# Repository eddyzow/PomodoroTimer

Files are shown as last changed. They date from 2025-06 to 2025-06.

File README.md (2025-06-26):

# PomodoroTimer
*i need to study and don't know how!*

# Build Photos





## Description

I've struggled with autism in early childhood and ADHD my entire life. It goes without saying that studying has never been the easiest thing for me. I've always been keen on finding interesting ways to improve study habits as a result! 

One of these strategies is the Pomodoro Timer, a special study method that involves 25 minutes of work and then 5 minutes of break. There's also the 52/17 method, which gives a 17-minute break after 52 minutes of studying. After not enjoying having to use a Pomodoro Timer on some random online websites, I decided that a beautiful physical device to allow me to use the Pomodoro Timer effectively would be a very cool thing to build for Highway! 

I decided to use a TFT LCD screen because I've never done any hardware work with displays nor have I done any work with SPI communication devices. This is the first of those for me!

Behold PomodoroTimer! A simple pomodoro timer with time adjustment function, swap between modes (normal, extended break, 52/17), and alarm. Powered by an Arduino Nano and contains minimalistic controls: just three momentary pushbutton switches and an EC11 rotary encoder on the side. Timer is shown through a 4.0" TFT LCD screen. Custom firmware written in Arduino. 

The case is slightly angled to present the buttons to the user in an ergonomic fashion. The entire design was created in Onshape CAD! Created for Hack Club's Highway program.

# Design Photos






# Case Design



# Wiring Diagram
V2: 
V1: 

# Firmware
Firmware was written in Arduino with a small amount of help from Gemini -- library being used is the Adafruit_ST7796S_kbv package and pin choices and wire routing is still my own!

# Bill of Materials
Note: cost is now less because I removed lots of stuff I could probably scavenge from another project and also optimized other products.

For a full BOM with links, visit https://docs.google.com/spreadsheets/d/1WLxYVnncp4hckqmgex7FmrPYrEnqb0mDVtI4Y9LR5lQ/edit?usp=sharing

| Item Name | Purpose | Item Source | Quantity | Unit Cost (includes taxes) | Cost |
|:---|:---|:---|---:|:---|:---|
| 5pc 12mm Momentary Pushbutton Switch | Buttons for mode, start/stop, and extend functions | Amazon | 1 | $8.59 | $8.59 |
| 2pc 12mm Latching Pushbutton Switch | Power button | Amazon | 1 | $7.43 | $7.43 |
| Clone Arduino Nano Board (2 Pack) | Logic / brains for the timer. Not sold individually!! | Amazon | 1 | $9.55 | $9.55 |
| 4.0" 480x320 TFT LCD Screen | Color screen to make the function of the timer beautiful  | Amazon | 1 | $18.37 | $18.37  |
| AA Battery Holder (4 AA) | Holds the batteries for the project | Amazon | 1 | $5.30 | $5.30 |
| 3.3V-5V Logic Level Shifter | Logic level shifter is necessary to communicate to the 3.3V LCD | Amazon | 1 | $7.95 | $7.95 |
| **TOTAL** | | | 6 | | **$57.19** |

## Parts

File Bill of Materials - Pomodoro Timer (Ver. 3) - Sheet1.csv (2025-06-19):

Bill of Materials / Pomodoro Timer
Eddy Zhao
Version 3.0 - 19 June 2025 | Update: removed a crap ton of stuff I could probably scavenge from another project + optimized BOM in light of the fact that i'm using amazon
Item Name | Purpose | Item Source | Quantity | Unit Cost (includes taxes) | Cost
5pc 12mm Momentary Pushbutton Switch | Buttons for mode, start/stop, and extend functions | Amazon | 1 | $8.59 | $8.59
2pc 12mm Latching Pushbutton Switch | Power button | Amazon | 1 | $7.43 | $7.43
Clone Arduino Nano Board (2 Pack) | Logic / brains for the timer. Not sold individually!! | Amazon | 1 | $9.55 | $9.55
4.0" 480x320 TFT LCD Screen | Color screen to make the function of the timer beautiful | Amazon | 1 | $18.37 | $18.37
AA Battery Holder (4 AA) | Holds the batteries for the project | Amazon | 1 | $5.30 | $5.30
3.3V-5V Logic Level Shifter | Logic level shifter is necessary to communicate to the 3.3V LCD | Amazon | 1 | $7.95 | $7.95
 |  |  |  |  | $0.00
 |  |  |  |  | $0.00
 |  |  |  |  | $0.00
 |  |  |  |  | $0.00
 |  |  |  |  | $0.00
 |  |  |  |  | $0.00
 |  |  |  |  | $0.00
TOTAL |  |  | 6 |  | $57.19
Already have:
EC11 Rotary Encoder + Knob
400-Point Breadboard
3D Printer Filament
M3 Screws and Nuts
Active Buzzer
Jumper Wires

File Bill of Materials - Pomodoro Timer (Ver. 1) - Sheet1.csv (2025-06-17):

Bill of Materials / Pomodoro Timer
Eddy Zhao
Version 1.0 - 17 June 2025
Item Name | Purpose | Item Source | Quantity | Unit Cost (includes taxes) | Cost
2pc 12mm Momentary Pushbutton Switch | Buttons for mode, start/stop, and extend functions | Amazon | 2 | $7.43 | $14.86
2pc 12mm Latching Pushbutton Switch | Power button | Amazon | 1 | $7.43 | $7.43
Clone Arduino Nano Board (3 Pack) | Logic / brains for the timer. Not sold individually!! | Amazon | 1 | $16.88 | $16.88
4.0" 480x320 TFT LCD Screen | Color screen to make the function of the timer beautiful | Amazon | 1 | $18.37 | $18.37
AA Battery Holder (4 AA) | Holds the batteries for the project | Amazon | 1 | $6.35 | $6.35
Soldering Iron | I didn't get a soldering iron grant yet... and this project requires it | Amazon | 1 | $12.74 | $12.74
Jumper Wires | To connect the various electronics on the project | Amazon | 1 | $7.42 | $7.42
3.3V-5V Logic Level Shifter | Logic level shifter is necessary to communicate to the 3.3V LCD | Amazon | 1 | $7.95 | $7.95
Passive Buzzer | To make sounds on input and alarm/timer | Amazon | 1 | $6.36 | $6.36
 |  |  |  |  | $0.00
 |  |  |  |  | $0.00
 |  |  |  |  | $0.00
 |  |  |  |  | $0.00
TOTAL |  |  | 10 |  | $98.36
Already have:
EC11 Rotary Encoder + Knob
400-Point Breadboard
3D Printer Filament
M3 Screws and Nuts

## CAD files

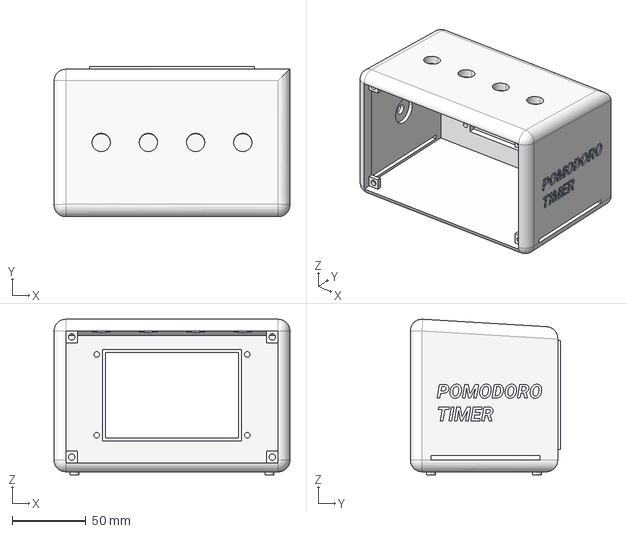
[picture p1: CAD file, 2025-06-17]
cad/Case - Pomodoro Timer.step
160.0 x 102.0 x 105.5 mm

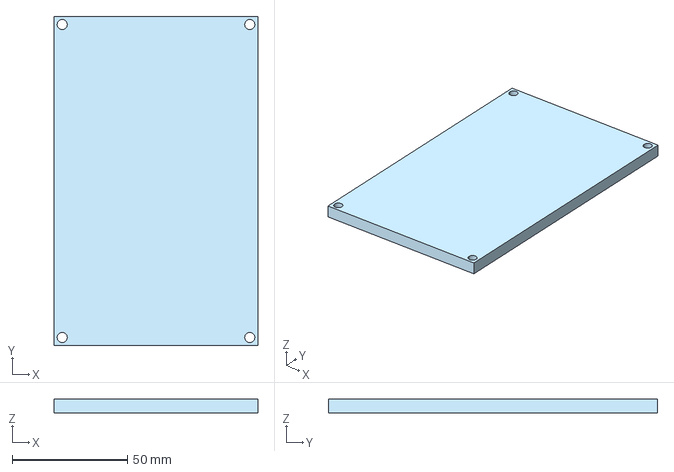
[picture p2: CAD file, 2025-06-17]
cad/Back Case Cover - Pomodoro Timer.step
88.5 x 143.0 x 6.00 mm

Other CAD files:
cad/Back Case Cover - Pomodoro Timer.stl
cad/Case - Pomodoro Timer.stl

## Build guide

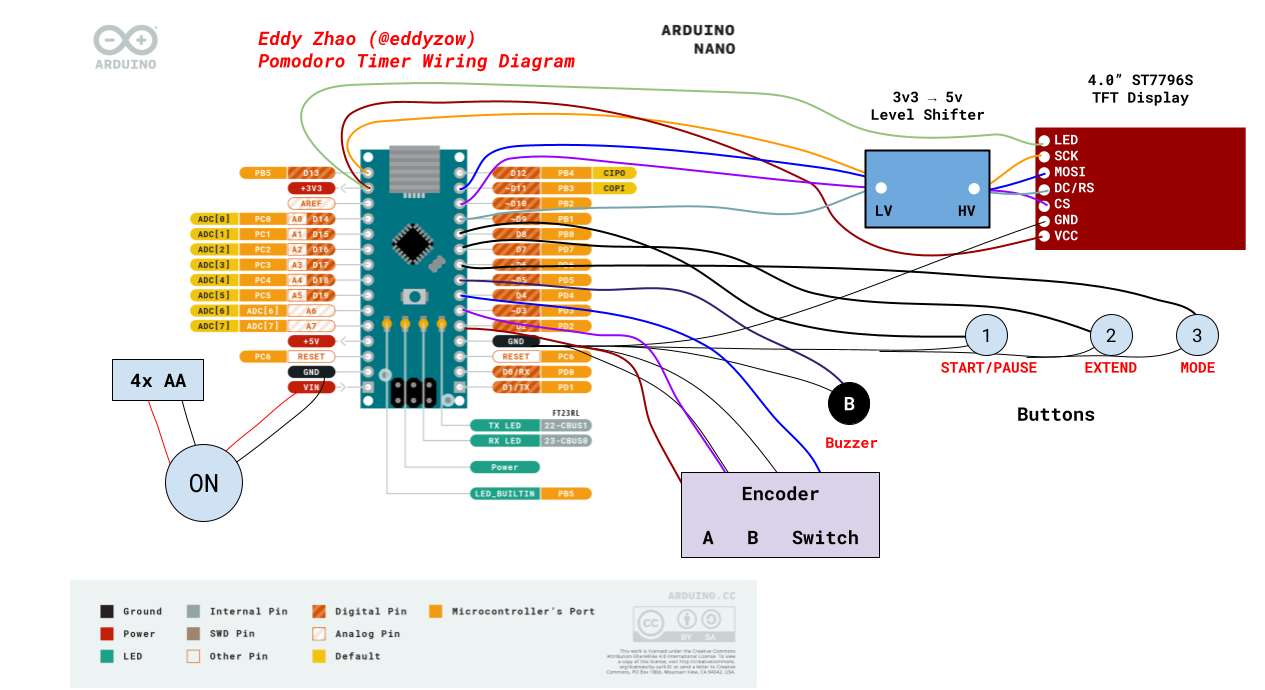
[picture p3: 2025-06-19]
Pomodoro Timer Wiring Diagram (1).png

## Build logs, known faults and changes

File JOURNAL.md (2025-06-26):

---
title: "PomodoroTimer"
author: "Eddy Zhao (@eddyzow)"
description: "A simple pomodoro timer with time adjustment function, swap between modes (normal, extended break, 52/17), and alarm."
created_at: "2025-06-16"
---

*Total hours spent: 20* | *Date started: 16 June 2025*

# Pomodoro Timer
_i need to study_

## entry #7 - 6/25

finally finished adding the battery system in, and the project is now complete! some final pictures:





it's been amazing getting to make this. see you in the next project!

_time spent during session: 3 hours_

## entry #6 - 6/25

finally received the parts and put it together! i'm on my phone typing this so no images but i'll add some tomorrow and submit hopefully! 

it's an amazing little device and i had to jump a few hurdles to get here such as pin #6 being dead and me forgetting to set the clock speed to the maximum for the display... but everything does work as intended! and i'm absolutely shocked that none of my solder work failed and pretty much everything worked on the first or second try.

i have the battery/power button system to implement last. so far i've just had it powered through usb-c, but that's about to change!

_time spent during session: 6 hours_

## entry #5 - 6/19

yesterday my project was not approved since the entire BOM was from amazon! thus, i went and removed some stuff and found a piezo buzzer i thought i had lost. and i was able to reduce the BOM by about $30!

i also updated the wiring diagram to show the direct wiring connections:



afterwards my project was approved -- can't wait to start!

_time spent during session: 1 hour_

## entry #4 - 6/17

finally, i've finished making the BOM and added pictures into the repo! i realized that the case is intended to come together in only two pieces (the back cover and the rest) -- i think this is great since my printer can print the entire case in one part (just with some supports). 



i'm looking forward to receiving my parts and getting to build this thing! it's been a great project and i hope to see you again in my next!

_time spent during session: 1 hour_

## entry #3 - 6/17

with some help from my best buddy (shh) i finished the firmware! it's based on the Adafruit_ST7796S_kbv package, a package that i'm not sure will seamlessly work with the TFT screen i'm using right now. if it doesn't work i'll just the TFT_eSPI library instead.

the code covers some of the tiny features of this timer that make it satisfying to use. for example, when you click the rotary encoder once, it flashes the minutes on the clock, then you can turn the encoder to increase or decrease the minutes of your timer! then when you click again, it will flash the seconds on the clock, so you can turn the encoder to change that! then when you click again, it sets the time! each click of a button has a sound feedback from the buzzer.

here are the modes (good luck reading code!)



and this about wraps it up for the building phase of this short project! i'll add the STEP files into the repo. the last thing i need to do is create the BOM and then submit! it should be well under the budget limit of $150 for highway projects.

_time spent during session: 2 hours_

## entry #2 - 6/17

i spent a big chunk of the day working on this, and it's nearing completion (wow that was a fast project)! i did LOTS of research to figure out the electronics and how they were going to play out in this little housing. first, i've decided to use an Arduino Nano since it's smaller and fits onto a breadboard. i manually figured out each pin that was being used and determined that i would be able to fit everything onto a nano. also, i realized that the rotary encoders I have are surface-mount -- however, there was a way to mount them using the given washer and nut! so there is a rotary encoder on the side for adjusting time. 

there are four buttons. The left one will be a latching pushbutton switch that turns on when you press it and off when you press it again. this is the power switch. the other three will be normal buttons with START/STOP, EXTEND, and MODE functions respectively. 

voila the finished (unwired) product!







_time spent during session: 6 hours_

## entry #1 - 6/16

i spent the last hour figuring out what i was going to use for the display, and i decided on this 4.0" TFT LCD (ST7796S) driven by an arduino nano. i then created a quick cad of the case, whuich does not contain any electronics components yet -- i will need to add the hole for the rotary encoder, buttons, power, etc. and all of it will fit inside this tight housing, likely powered by four AA batteries. if needed i will enlarge the housing. i will also add a hidden message inside / outside the case! 

tomorrow i will look at electronics and try to get some real stuff going on. i anticipate this will be a short project but i'll still learn a lot because i've never used SPI before and i've also never played with displays or buzzers before!



_time spent during session: 1 hour_

## entry #0 - 6/16

welcome back! it's time for my FOURTH highway project! i can't believe i'm starting another one even though none of my first three have been built yet -- shame on long wait times for project approval and shipping. :(

this time, i'll be building something really necessary for me especially as i'm going into college. introducing... the Pomodoro Timer!

if you haven't heard of the pomodoro system, you study for 25 minutes, take a 5 min break, and repeat. it's supposed to give you the best study feel, and i thought a physical device to be the timer would be intersting.

i envision getting to use the rest of my rotary encoders and extra keyboard switches to build this, so the budget will hopefully be low! there will be other modes on the timer such as 52/17 (52 min work, 17 min break) for people like me who have a hard time locking in, and when locked in, a hard time locking out (ADHD people!)

that'll be it for this entry. i'm going to begin creating my design. no PCBs - i'm just going to use a good old breadboard for this one.

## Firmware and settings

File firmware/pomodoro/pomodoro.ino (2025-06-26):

#include <Adafruit_GFX.h>
#include <Adafruit_ST7796S_kbv.h>
#include <SPI.h>
#include <Encoder.h>

#include "Fonts/FreeSansBold24pt7b.h"

// remember logic shifter!!

#define TFT_CS   10
#define TFT_DC   9
#define TFT_RST  -1 // Connect display RST to Nano RST pin for hardware reset.
#define ENCODER_A   2 // Interrupt Pin
#define ENCODER_B   3 // Interrupt Pin
#define ENCODER_SW  4
#define START_PAUSE_BUTTON  8
#define EXTEND_BUTTON       7
#define MODE_BUTTON         A1
#define BUZZER_PIN  5
#define WORK_BG     0x000F  // A very dark, deep blue
#define BREAK_BG    0x0410  // A calming, dark teal
#define IDLE_BG     0x4208  // A medium-dark grey
#define WHITE       0xFFFF
#define YELLOW      0xFFE0

Adafruit_ST7796S_kbv tft(TFT_CS, TFT_DC, TFT_RST);
Encoder myEncoder(ENCODER_A, ENCODER_B);
enum OperatingMode { MODE_POMODORO, MODE_52_17, MODE_ALARM };
OperatingMode currentMode = MODE_POMODORO;
enum TimerState {
  STATE_IDLE, STATE_RUNNING_WORK, STATE_RUNNING_BREAK, STATE_PAUSED,
  STATE_SETTING_MINUTES, STATE_SETTING_SECONDS, STATE_ALARM_TRIGGERED
};
TimerState currentState = STATE_IDLE;
TimerState pausedState;

unsigned long timeLeftInSeconds = 0;
unsigned long workTimeSetting = 25 * 60;
unsigned long breakTimeSetting = 5 * 60;
unsigned long lastSecondMillis = 0;

long encoderPosition  = 0;
bool isBlinking = false;
unsigned long lastBlinkMillis = 0;

char lastDisplayedTime[6] = "00:00";
char lastSetTimeString[6] = "00:00";
uint16_t currentBgColor = IDLE_BG;

void buzz(int count, int duration, int frequency = 1175);

void setup() {
  delay(500); 

  pinMode(ENCODER_SW, INPUT_PULLUP);
  pinMode(START_PAUSE_BUTTON, INPUT_PULLUP);
  pinMode(EXTEND_BUTTON, INPUT_PULLUP);
  pinMode(MODE_BUTTON, INPUT_PULLUP);
  pinMode(BUZZER_PIN, OUTPUT);

  tft.begin(8000000); 
  tft.setRotation(1);

  buzz(1, 100, 1175); 
  resetToIdle();
}

void loop() {
  handleInputs();

  if (currentState == STATE_RUNNING_WORK || currentState == STATE_RUNNING_BREAK) {
    updateTimer();
  }
  
  if (currentState == STATE_SETTING_MINUTES || currentState == STATE_SETTING_SECONDS) {
    handleTimeSetting();
    handleBlinking();
  }
}

void updateTimer() {
  if (millis() - lastSecondMillis >= 1000) {
    lastSecondMillis = millis();
    if (timeLeftInSeconds > 0) {
      timeLeftInSeconds--;
      drawTime();
    } else {
      handleTimerEnd();
    }
  }
}

void handleTimerEnd() {
  if (currentMode == MODE_POMODORO || currentMode == MODE_52_17) {
    if (currentState == STATE_RUNNING_WORK) {
      buzz(2, 150, 1500); 
      currentState = STATE_RUNNING_BREAK;
      timeLeftInSeconds = breakTimeSetting;
    } else {
      buzz(1, 200, 1175); 
      currentState = STATE_RUNNING_WORK;
      timeLeftInSeconds = workTimeSetting;
    }
  } else {
    currentState = STATE_ALARM_TRIGGERED;
    while (true) {
      buzz(1, 500, 2000); 
      delay(1000);
      if (digitalRead(START_PAUSE_BUTTON) == LOW || digitalRead(EXTEND_BUTTON) == LOW ||
          digitalRead(MODE_BUTTON) == LOW || digitalRead(ENCODER_SW) == LOW) {
        break;
      }
    }
    resetToIdle();
  }
  drawScreenLayout();
}

void resetToIdle() {
  currentState = STATE_IDLE;
  switch (currentMode) {
    case MODE_POMODORO:
      workTimeSetting = 25 * 60; breakTimeSetting = 5 * 60; break;
    case MODE_52_17:
      workTimeSetting = 52 * 60; breakTimeSetting = 17 * 60; break;
    case MODE_ALARM:
      workTimeSetting = 10 * 60; breakTimeSetting = 0; break;
  }
  timeLeftInSeconds = workTimeSetting;
  drawScreenLayout();
}

void handleInputs() {
  if (digitalRead(START_PAUSE_BUTTON) == LOW) {
    delay(50);
    if (digitalRead(START_PAUSE_BUTTON) == LOW) {
      buzz(1, 50, 1175); 
      if (currentState == STATE_IDLE) currentState = STATE_RUNNING_WORK;
      else if (currentState == STATE_RUNNING_WORK || currentState == STATE_RUNNING_BREAK) {
        pausedState = currentState; currentState = STATE_PAUSED;
      } else if (currentState == STATE_PAUSED) currentState = pausedState;
      drawScreenLayout();
      while (digitalRead(START_PAUSE_BUTTON) == LOW);
    }
  }

  if (digitalRead(EXTEND_BUTTON) == LOW) {
    delay(50);
    if (digitalRead(EXTEND_BUTTON) == LOW) {
      if (currentState != STATE_IDLE && currentState != STATE_SETTING_MINUTES && currentState != STATE_SETTING_SECONDS) {
        buzz(1, 50, 1175);
        timeLeftInSeconds += 5 * 60;
        drawTime();
      }
      while (digitalRead(EXTEND_BUTTON) == LOW);
    }
  }

  if (digitalRead(MODE_BUTTON) == LOW) {
    delay(50);
    if (digitalRead(MODE_BUTTON) == LOW) {
      if (currentState == STATE_IDLE || currentState == STATE_PAUSED) {
        buzz(1, 50, 1175); 
        currentMode = static_cast<OperatingMode>((currentMode + 1) % 3);
        resetToIdle();
      }
      while (digitalRead(MODE_BUTTON) == LOW);
    }
  }

  if (digitalRead(ENCODER_SW) == LOW) {
    delay(50);
    if (digitalRead(ENCODER_SW) == LOW) {
      if (currentState == STATE_IDLE || currentState == STATE_PAUSED) {
        buzz(1, 50, 1175);
        currentState = STATE_SETTING_MINUTES;
        drawSettingScreenLayout();
        myEncoder.write((timeLeftInSeconds / 60) * 4);
        encoderPosition = myEncoder.read() / 4;
      } else if (currentState == STATE_SETTING_MINUTES) {
        buzz(1, 50, 1175);
        currentState = STATE_SETTING_SECONDS;
        drawSettingTime();
        myEncoder.write((timeLeftInSeconds % 60) * 4);
        encoderPosition = myEncoder.read() / 4;
      } else if (currentState == STATE_SETTING_SECONDS) {
        if (timeLeftInSeconds == 0) timeLeftInSeconds = 1;
        workTimeSetting = timeLeftInSeconds;
        buzz(2, 75, 1568);
        currentState = STATE_IDLE;
        drawScreenLayout();
      }
      while (digitalRead(ENCODER_SW) == LOW);
    }
  }
}

void handleTimeSetting() {
    long newEncoderPos = myEncoder.read() / 4;
    long oldEncoderPos = encoderPosition;
    
    if (newEncoderPos != oldEncoderPos) {
        if (currentState == STATE_SETTING_MINUTES) {
            long minutes = timeLeftInSeconds / 60;
            if (newEncoderPos < oldEncoderPos) minutes++;
            else minutes--;
            if (minutes < 0) minutes = 59;
            if (minutes > 59) minutes = 0;
            timeLeftInSeconds = (minutes * 60) + (timeLeftInSeconds % 60);
        } else if (currentState == STATE_SETTING_SECONDS) {
            long seconds = timeLeftInSeconds % 60;
            if (newEncoderPos < oldEncoderPos) seconds++;
            else seconds--;
            if (seconds < 0) seconds = 59;
            if (seconds > 59) seconds = 0;
            timeLeftInSeconds = (timeLeftInSeconds / 60) * 60 + seconds;
        }
        
        isBlinking = true;
        lastBlinkMillis = millis();
        drawSettingTime();
        encoderPosition = newEncoderPos;
    }
}
void drawScreenLayout() {
  currentBgColor = IDLE_BG;
  if (currentState == STATE_RUNNING_WORK || currentState == STATE_ALARM_TRIGGERED) currentBgColor = WORK_BG;
  if (currentState == STATE_RUNNING_BREAK) currentBgColor = BREAK_BG;
  tft.fillScreen(currentBgColor);

  tft.setFont();
  tft.setCursor(10, 10);
  tft.setTextColor(WHITE);
  tft.setTextSize(2);
  switch (currentMode) {
    case MODE_POMODORO: tft.print("Pomodoro"); break;
    case MODE_52_17:    tft.print("52/17");    break;
    case MODE_ALARM:    tft.print("Alarm");    break;
  }

  if (currentState == STATE_PAUSED) {
    tft.setCursor(10, 35);
    tft.print("PAUSED");
  }

  drawTime();
}

void drawTime() {
  int minutes = timeLeftInSeconds / 60;
  int seconds = timeLeftInSeconds % 60;
  char timeStr[6];
  sprintf(timeStr, "%02d:%02d", minutes, seconds);
  
  tft.setFont(&FreeSansBold24pt7b);
  int16_t x1, y1;
  uint16_t w, h;
  tft.getTextBounds("00:00", 0, 0, &x1, &y1, &w, &h);
  int16_t x = (tft.width() - w) / 2;
  int16_t y = (tft.height() + h) / 2;

  tft.setTextColor(currentBgColor);
  tft.setCursor(x, y);
  tft.print(lastDisplayedTime);

  tft.setTextColor(WHITE);
  tft.setCursor(x, y);
  tft.print(timeStr);
  
  strcpy(lastDisplayedTime, timeStr);
}

void drawSettingTime(){
    int minutes = timeLeftInSeconds / 60;
    int seconds = timeLeftInSeconds % 60;
    
    char minStr[3]; sprintf(minStr, "%02d", minutes);
    char secStr[3]; sprintf(secStr, "%02d", seconds);
    char fullStr[6]; sprintf(fullStr, "%s:%s", minStr, secStr);
    
    uint16_t minColor = (currentState == STATE_SETTING_MINUTES && isBlinking) ? YELLOW : WHITE;
    uint16_t secColor = (currentState == STATE_SETTING_SECONDS && isBlinking) ? YELLOW : WHITE;

    tft.setFont(&FreeSansBold24pt7b);
    int16_t x1, y1;
    uint16_t w, h;
    tft.getTextBounds("00:00", 0, 0, &x1, &y1, &w, &h);
    int16_t x = (tft.width() - w) / 2;
    int16_t y = (tft.height() + h) / 2;

    tft.setTextColor(IDLE_BG);
    tft.setCursor(x, y);
    tft.print(lastSetTimeString);

    tft.setCursor(x, y);
    
    tft.setTextColor(minColor);
    tft.print(minStr);

    tft.setTextColor(WHITE);
    tft.print(":");

    tft.setTextColor(secColor);
    tft.print(secStr);

    strcpy(lastSetTimeString, fullStr);
}

void drawSettingScreenLayout() {
    currentBgColor = IDLE_BG;
    tft.fillScreen(currentBgColor);
    tft.setFont();
    tft.setTextSize(2);
    tft.setCursor(10,10);
    tft.setTextColor(WHITE);
    tft.print("Set Time:");
    sprintf(lastSetTimeString, "%02d:%02d", (int)(timeLeftInSeconds / 60), (int)(timeLeftInSeconds % 60));
    drawTime();
}

void handleBlinking() {
  if (millis() - lastBlinkMillis > 400) {
    lastBlinkMillis = millis();
    isBlinking = !isBlinking;
    drawSettingTime();
  }
}

void buzz(int count, int duration, int frequency = 1175) {
  for (int i = 0; i < count; i++) {
    tone(BUZZER_PIN, frequency, duration);
    if(count > 1) delay(duration + 50);
  }
}

#include "Fonts/FreeSansBold24pt7b.h"

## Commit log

2025-06-18 Update and rename Bill of Materials - Pomodoro Timer (Ver. 1) - Sheet1.csv to Bill of Materials - Pomodoro Timer (Ver. 2) - Sheet1.csv
    [Bill of Materials - Pomodoro Timer (Ver. 2) - Sheet1.csv]
2025-06-19 Add files via upload
    added STL versions of the same cad files for back case cover and case
    [Back Case Cover - Pomodoro Timer.stl, Case - Pomodoro Timer.stl]
